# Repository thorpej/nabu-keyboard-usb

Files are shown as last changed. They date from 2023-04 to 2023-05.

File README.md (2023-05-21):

# A NABU Keyboard-to-USB Adapter

(Update: I made a short video about this project!  You can view it
[here](https://youtu.be/F3Tp9NLZv1M).)

This is an adapter that lets you connect a [NABU](https://nabu.ca/) PC
keyboard to any modern computer using USB.  In addition to the keyboard,
it reports the Atari-style joysticks as USB HID gamepads (each as a single
D-pad / hat switch with a single "A" button).

Most of the NABU keys are supported in the obvious way, but it's helpful
to understand how the NABU keyboard works: The keyboard, for the most part,
sends ASCII codes for the keys that are pressed.  It handles CTRL, SHIFT,
and CAPS-LOCK all on its own.  It does not send separate key-down and key-up
events for the standard keys, and it implements key-repeat itself as well.
There are some exceptions, however: the arrow keys (including the **<|||**
and **|||>** keys), **YES**, **NO**, **SYM**, **PAUSE** and **TV/NABU** keys
_do_ send separate key-down and key-up events, and are unaffected by the
normal keyboard modifier keys.  These so-called "special keys" are mapped
to various HID key events as described below.

The physical interface to the NABU keyboard is a DIN-6 connector carrying
a power rail and an RS422 differential transmit line.  The RS422 serial
line runs at 6992 baud, with 8 data bits, 1 stop bit, and no parity.  The
odd-ball bit rate is due to the way the clock is derived; the main clock
frequency in the keyboard is 3.58MHz (the NTSC colorburst frequency), and
the MC6803 microcontroller inside the keyboard internally divides the clock
by 4 to derive its "E" clock.  The firmware in the keyboard then configures
the MC6803's on-board UART to divide E by 128 for the baud clock.
Communication with the keyboard is unidirectional; it is not possible to
send commands to the keyboard.

The keyboard is powered by a nominally-12V-but-actally-9V power supply
provided by the NABU.  The keyboard power comes from the NABU's 12V rail,
but is fed to the keyboard through a large power resistor on the NABU's
mainboard, which drops the voltage to ~9V at the keyboard's steady-state
current draw (documentation says 300mA, but my bench supply tells me
310-320mA).  The keyboard contains an on-board regulator to provide its
own +5V power rail.  In any case, a 9V DC power brick that can supply at
least 500mA should be perfect for the job.  The adapter controls the power
to the NABU using a small power MOSFET connected between the 9V return from
the keyboard and and negative terminal of the power supply.

## How the adapter works

The adapter utilizes the built-in UART and GPIO functionality of the
Raspberry Pi Pico microcontroller.  UART0 is used as the adapter's console
(115200 @ 8N1), UART1 is used to receive data from the keyboard, and one
GPIO pin is used to control the power to the keyboard.  Another GPIO is
sampled at start-up time to enable debug messages; debugging is enabled
when the jumper is installed.

When the adapter starts up, it performs all of the initialization required
and then starts up the second core on the Pico to pull data in from the
keyboard.  This loop running on the second core determines if the data is
for the keyboard or one of the joysticks, and then adds the data byte to
the appropriate input queue.

Meanwhile, the primary core powers up the keyboard and enters its main loop.
This main loop performs 4 basic tasks:
* Blinking the status LED on the Pico to indicate various states of the
  adapter.
* Performing a health check of the keyboard.
* Processing incoming data from the keyboard and generating the appropriate
  USB HID report sequences.
* Calling into the TinyUSB stack to perform device-side USB processing.

### LED task

The LED task is pretty simple and just provides a simple way of reporting
the current status of the adapter at-a-glance.  There are 4 blinking sequences:
* Fast blinking to indicate the adapter is waiting for the host to establish
  a USB session.
* Medium blinking to indicate the adapter is connected to the host but waiting
  for the keyboard to show signs of life.
* A heatbeat pattern to indicate everything is operating normally.
* A slow blinking to indicate the adapter has been suspended and the keyboard
  powered off.

### Keyboard health check task

The health check task (a.k.a. "deadcheck") checks to make sure that we've
heard from the keyboard within the last 5 seconds.  When idle, the keyboard
sends a "ping" approximately every 3.7 seconds.  Whenever the keyboard reader
running on the second core receives a byte of data from the keyboard, it
updates a timestamp, which is checked in deadcheck routine.  If the keyboard
fails to check in for two deadcheck intervals, the adapter reboots the
keyboard by cycling power.

### Data processing task

The data processing task (called _hid_task()_ in the code) pulls data
enqueued by the keyboard reader thread and performs the processing necessary
to generate USB HID report sequences.  In addition to regular keystrokes,
error messages from the keyboard and joystick data are also processed here,
as is remote-host-wakeup if the host system is suspended.

Error processing is actually performed all the time, because the periodic
ping from the keyboard comes in as an error message, as does the notification
of a successful power-on-reset.  Additionally, there are internal hardware
errors (bad RAM / ROM, etc.) as well as user errors (too many keys pressed)
that are reported.  Hardware errors result in rebooting the keyboard by
cycling power.

Because the NABU keyboard generates only a single byte for most key presses,
this task has to generate HID report sequences to correctly report the key.
For example, if we get "A" from the keyboard, we have to generate a sequence
of 4 HID reports: _SHIFT_, _SHIFT_ + _A_, _SHIFT_, _(none)_.  These sequences
are encoded in a table indexed by NABU keyboard code.  All of the regular
keys end with a _(none)_ report.

The special keys are a little different.  They send individual key-down and
key-up events to the adapter, so we are able to simply mirror that behavior
to the host.  Additionally, two of the special keys have been mapped to key
modifiers: **SYM** is mapped to **Meta** (a.k.a. Windows, Command, or GUI).
and the **TV/NABU** key is mapped to **Alt** (a.k.a. Option on Macs).  The
adapter tracks the state of those keys and includes them as modifiers in
keyboard HID reports.

Much to the chargin of Unix users worldwide, the NABU keyboard lacks a
backslash key.  On US keyboards, this key is also used for the "pipe"
character (SHIFT + backslash).  We steal the **YES** and **NO** keys on
the NABU keyboard for these characters: **YES** for pipe, **NO** for
backslash (we have to use two different special keys since special keys
are not affected by the SHIFT keys).  Luckily, because we're using a
special key for **Alt**, we can still type guillemets on a Mac by using
**TV/NABU** plus the **YES** and **NO** keys.  _«Absolument merveilleux !»,
a-t-il déclaré._

Ok! To summarize the special keys:
* **Up**, **Down**, **Left**, and **Right** arrow keys map to their regular
  US keyboard equivalents.
* **<|||** maps to **Page Up** and **|||>** maps to **Page Down** (very
  useful for scrolling in Terminal on macOS).
* **SYM** maps to **Meta**, a.k.a. **Windows**, **Command**, **GUI**,
  **⌘**, etc.
* **TV/NABU** maps to **Alt**, a.k.a. **Option**, **⌥**, etc.
* **NO** maps to **\\**, a.k.a. backslash.
* **YES** maps to **|**, a.k.a. pipe, vertical bar, etc. 

### TinyUSB device task

This is just a call into the TinyUSB library that performs device-side
processing.  From here, various callbacks back into the main adapter code
can be made to fetch descriptors, reports, and set suspend/resume state.

## The hardware

The hardware is very simple and is centered around the Raspberry Pi Pico
microcontroller board, wich provides a UART for the debug console, a UART
for the keyboard interface, the USB interface to the host, and general-
purpose I/O facilities for configuration of the adapter and control of the
keyboard's power supply.

Note that the adapter board has 3 separate power rails: +5V (supplied by
the USB host), +3V3 (from the Pico's on-board regulator), and +9V (from an
external DC power brick, for the keyboard).

### Keyboard input

The keyboard uses RS422 differential signalling, so a SN75176A differential
bus transciever is used to convert the keyboard signalling to a TTL-compatible
signal.  The transient suppression circuitry mimics that present in the NABU
PC.

The output of the SN75176A is at 5V TTL logic levels, but the Pico's I/O
interface operates at 3V3 CMOS logic levels, so a level shifter must be
used.  I just picked the 74LVC245 bus transciever for the job because I
had plenty of them handy, even though it's slight overkill.

The 74LVC245's output is connected to the Rx pin of UART1 on the Pico.
That's pretty much it for the keyboard input.

### Keyboard power supply / control

The board has a 5.5mm x 2.1mm center-positive barrel jack for power input
from an external 9V power brick.  There is a diode in-series with the
positive terminal as reverse-polarity protection.  The positive terminal
from this supply goes stright to the keyboard.  The power return line
from the keyboard is attached to the drain of an IRLU110PBF power MOSFET,
and the MOSFET's source is then connected to the negative terminal of the
supply, which is also connected to the board's ground plane.  The gate is
normally pulled down, but can be driven high by a pin on the Pico to complete
the circuit and power on the keyboard.  The IRLU110PBF was selected for its
current rating, relatively low as far as power MOSFETs go (1V) Vgs threshold,
and < 1 Ohm Rds-ON.  There's nothing particularly special about it otherwise,
and this application isn't especially demanding, so feel free to substitute
your favorite MOSFET (so long as it is in a TO-251-3 package and has a GDS
pin configuration).

### Pin headers

There are 2 pin headers on the board:
* J1 provides access to UART0 on the Pico, so you can see informational or
  debug messages that are logged by the firmware running on the Pico.
* JP1, when connected, enables those fairly verbose debugging messages.  The
  pin is sampled when the adapter starts up, so enabling them requires
  unplugging the adapter from USB and plugging it back in after connecting
  the jumper.

### The board layout

I am definitely an amateur when it comes to PCB design and layout, but I did
try to keep the board fairly small while still making it easy to assemble
(all through-hole parts except for the tab on the power MOSFET which you don't
even _really_ have to solder if that's your preference).  The footprints for
the decoupling caps and suppression caps are fairly forgiving, so if you have
1nF and 100nF caps in your parts bin that fit the footprint, by all means use
them.

You will need to put downward-facing pin headers onto your Pico and install
female pin header stand-offs onto the board.  This is because I squeezed the
power MOSFET and its pulldown resistor under the Pico.  This isn't really
much of a compromise in height since there's a big ol' DIN-6 socket at the
back of the board anyhow.  (The board size is largely dictated by the external
connections.)

Space for sockets for the DIP ICs is provided because I like to use them.
Feel free to elide if that's what floats your boat.

There are a couple of "special" parts on the board:
* The resistors used on the board are fairly small for through-hole resistors,
  selected to reduce space requirements.  Happily, they're readily available
  from Mouser.
* The DIN-6 socket is harder to get than it should be (plenty of panel-mount
  flavors, but not PCB-mount, sigh).  The one I selected was the CLIFF
  FC680806, available from Newark / element14 / Farnell.  The Hirschmann
  930 778-200 may also work, and there's a
  [no-name version on Amazon](https://www.amazon.com/dp/B015IGPKPK)
  that looks like a copy of the CLIFF part.

I expect to make small tweaks to the board over time, but mainly just to get
alignment of various externally-facing parts Just Right(tm) in the event that
some enterprising individual wants to make a 3D-printed enclosure for it
(**_hey, if you want to do this, please get in contact with me!_**).

In addition to the KiCad design files, a PDF version of the schematic and
board images are also provided, along with the Gerber files needed to have
the board made by your favorite PCB fabrication house.

### So what do I need to build one of these things?

Most of the parts required are bog-standard, available from lots of places.
The Raspberry Pi Pico, the DIP sockets, and the male and female pin headers
can all be acquired from Amazon.  If you want nice machined DIP sockets
instead of the cheap stamped kind, you can get those from
[Phoenix Enterprises](https://www.peconnectors.com/sockets-dip-ic-machined/),
but they have a minimum order.  The ceramic capacitors are basic parts,
but I've provided links to specific parts that I know will fit the board
footprints.  I've done the same with the resistors.

* 1 - Raspberry Pi Pico
* 2 - 20x1 2.54mm pin header (for the Pico)
* 1 - 2x1 2.54mm pin header (optional) (for debug jumper)
* 1 - 3x1 2.54mm pin header (optional) (for debug console)
* 2 - 20x1 2.54mm female pin header (to receive the Pico - _cannot be
  low-profile - space beneath the Pico is required_)
* 1 - DIP-20 socket (optional)
* 1 - DIP-8 socket (optional)
* 1 - [SN74LVC245](https://www.mouser.com/ProductDetail/595-SN74LVC245ANE4)
  in DIP-20 package
* 1 - [SN75176A](https://www.mouser.com/ProductDetail/595-SN75176AP) in
  DIP-8 package
* 1 - [IRLU110PBF](https://www.mouser.com/ProductDetail/844-IRLU110PBF) or
  equivalent power MOSFET in TO-251-3 package with GDS pin configuration
* 2 - [100nF / 0.1µF ceramic capacitor](https://www.mouser.com/ProductDetail/581-SR215E104MAR)
* 2 - [1nF / 1000pF ceramic capacitor](https://www.mouser.com/ProductDetail/581-SR215A102JARTR1)
* 1 - [180 Ohm resistor](https://www.mouser.com/ProductDetail/603-MFR50SFTE52-180R) that fits in a DIN0207 vertical footprint.
* 1 - [10K Ohm resistor](https://www.mouser.com/ProductDetail/603-MFR50SFTE52-10K) that fits in a DIN0207 horizontal footprint.
* 1 - 1N4001 diode in the standard package.  You can actually use whatever diode floats your boat here (it's not involved in
  any switching, merely used for reverse polarity protection), so long as it has > 18V reverse voltage rating and a 500mA current
  rating.
* 1 - [PCB-mount 5.5mm x 2.1mm DC barrel jack](https://www.mouser.com/ProductDetail/163-179PH-EX)
* 1 - [PCB-mount DIN-6 jack, CLIFF FC680806 or equivalent](https://www.newark.com/cliff-electronic-components/fc680806/din-audio-video-conn-jack-6pos/dp/99AC9154).  Also available [here!](https://www.tme.com/us/en-us/details/fc680806/din-connectors/cliff/d6-fc680806/)
* 1 - [9V @ 500mA-or-better DC power brick with 5.5mm x 2.1mm barrel connector](https://www.mouser.com/ProductDetail/490-SWI12-9-N-P5)
* 1 - Micro-USB cable for connecting the adapter to your computer.

### Assembling the board

You might have your own favorite way of putting these things together.  If
so, hey, you do you!  But for those of you who don't, let me recommend a
few basic pointers that will help making the going a little easier.  I'm
going to assume that you already know the basics of soldering.

First, it's best to assemble the lowest-profile components first, increasing
the height of the board as you go along.  With that in mind, here is the
order I would recommend:

1. R1 and Q1 (the parts that sit beneath the Pico)
2. D1
3. U1 and U3 (or their sockets)
4. C1, C2, C3, and C4
5. R2 (the vertically-mounted resistor next to C3 and C4)
6. Female pin heders for U2 (the Pico)
7. J1 and JP1 (the male pin headers)
8. J3 (the DC barrel jack)
9. J2 (the DIN-6 jack)

If you already installed the pin headers into your Pico, or bought the Pico
with the pin headers pre-installed (hopefully with the long end of the pins
facing downwards), then cool!  Otherwise, a trick that makes it easy is to
place the pin headers into the Pico (with the plastic holder on the bottom
of the Pico and the short end of the pins poking through the Pico board) and
then press that as a unit into the female headers installed on the adapter
board.  That will hold everything steady while you solder the pin headers
to the Pico itself.

### Programming the Pico with the NABU Keyboard to USB firmware

Ok, so you've built the board, now you need to get the firmware onto the Pico.
This is easy!  There's a small button on the Pico board.  What you need to do
is to hold that button down while you connect the Pico to your computer using
the USB cable.  When you do that, the Pico will appear on your computer as a
hard drive with a FAT file system on it named "RPI-RP2" (exactly how this
appears on your computer is left as an exercise to the reader).  All you need
to do is copy the provided **_nabu_keyboard_usb.uf2_** file onto that file
system _et voilà!_ your Pico is programmed and has now attached itself as a
USB HID device with 1 keyboard interface and 2 game pad interfaces!

Once you've programmed the Pico, you're all set.  At this point, I recommend
unplugging it from the computer before attaching the 9V power brick and NABU
keyboard.  Once everything is cabled up, plug the Pico back into your computer
and enjoy typing on those sweet, sweet ALPS key switches!

I hope you have fun with your NABU and I hope you enjoy this silly little
project of mine!  If you end up playing with it, I'd love to hear from you!
You can find me on [Mastodon](https://mastodon.sdf.org/@thorpej)
and on [Twitter](https://twitter.com/thorpej) (for as long as it lasts,
anyway).

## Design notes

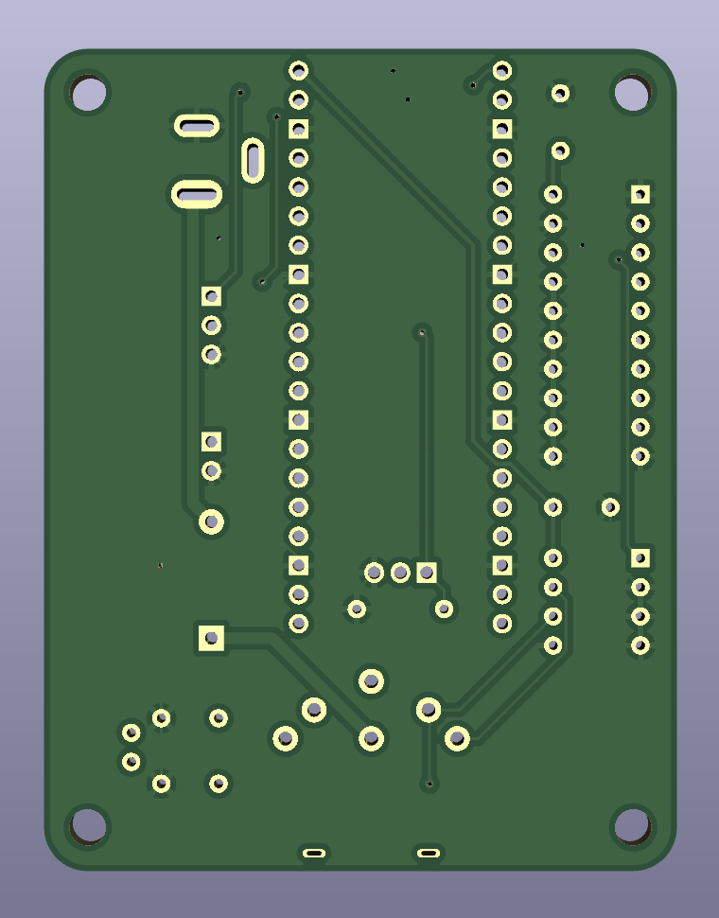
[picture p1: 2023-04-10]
design-files/nabu-keyboard-usb-pcb-back.png

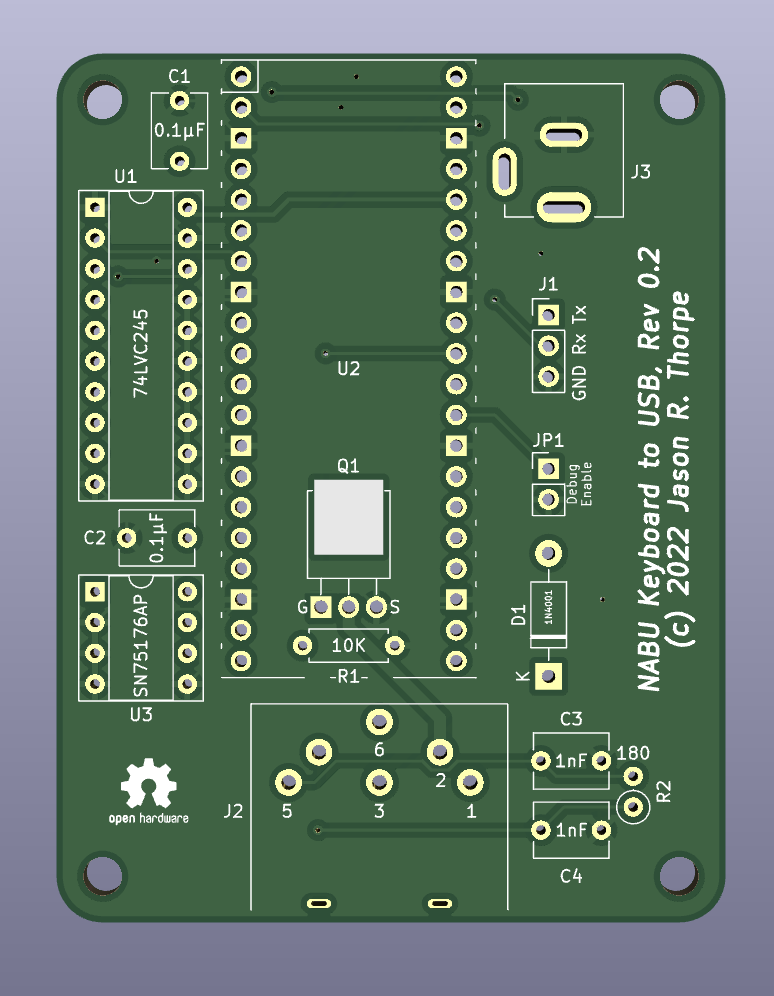
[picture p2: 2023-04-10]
design-files/nabu-keyboard-usb-pcb-front.png

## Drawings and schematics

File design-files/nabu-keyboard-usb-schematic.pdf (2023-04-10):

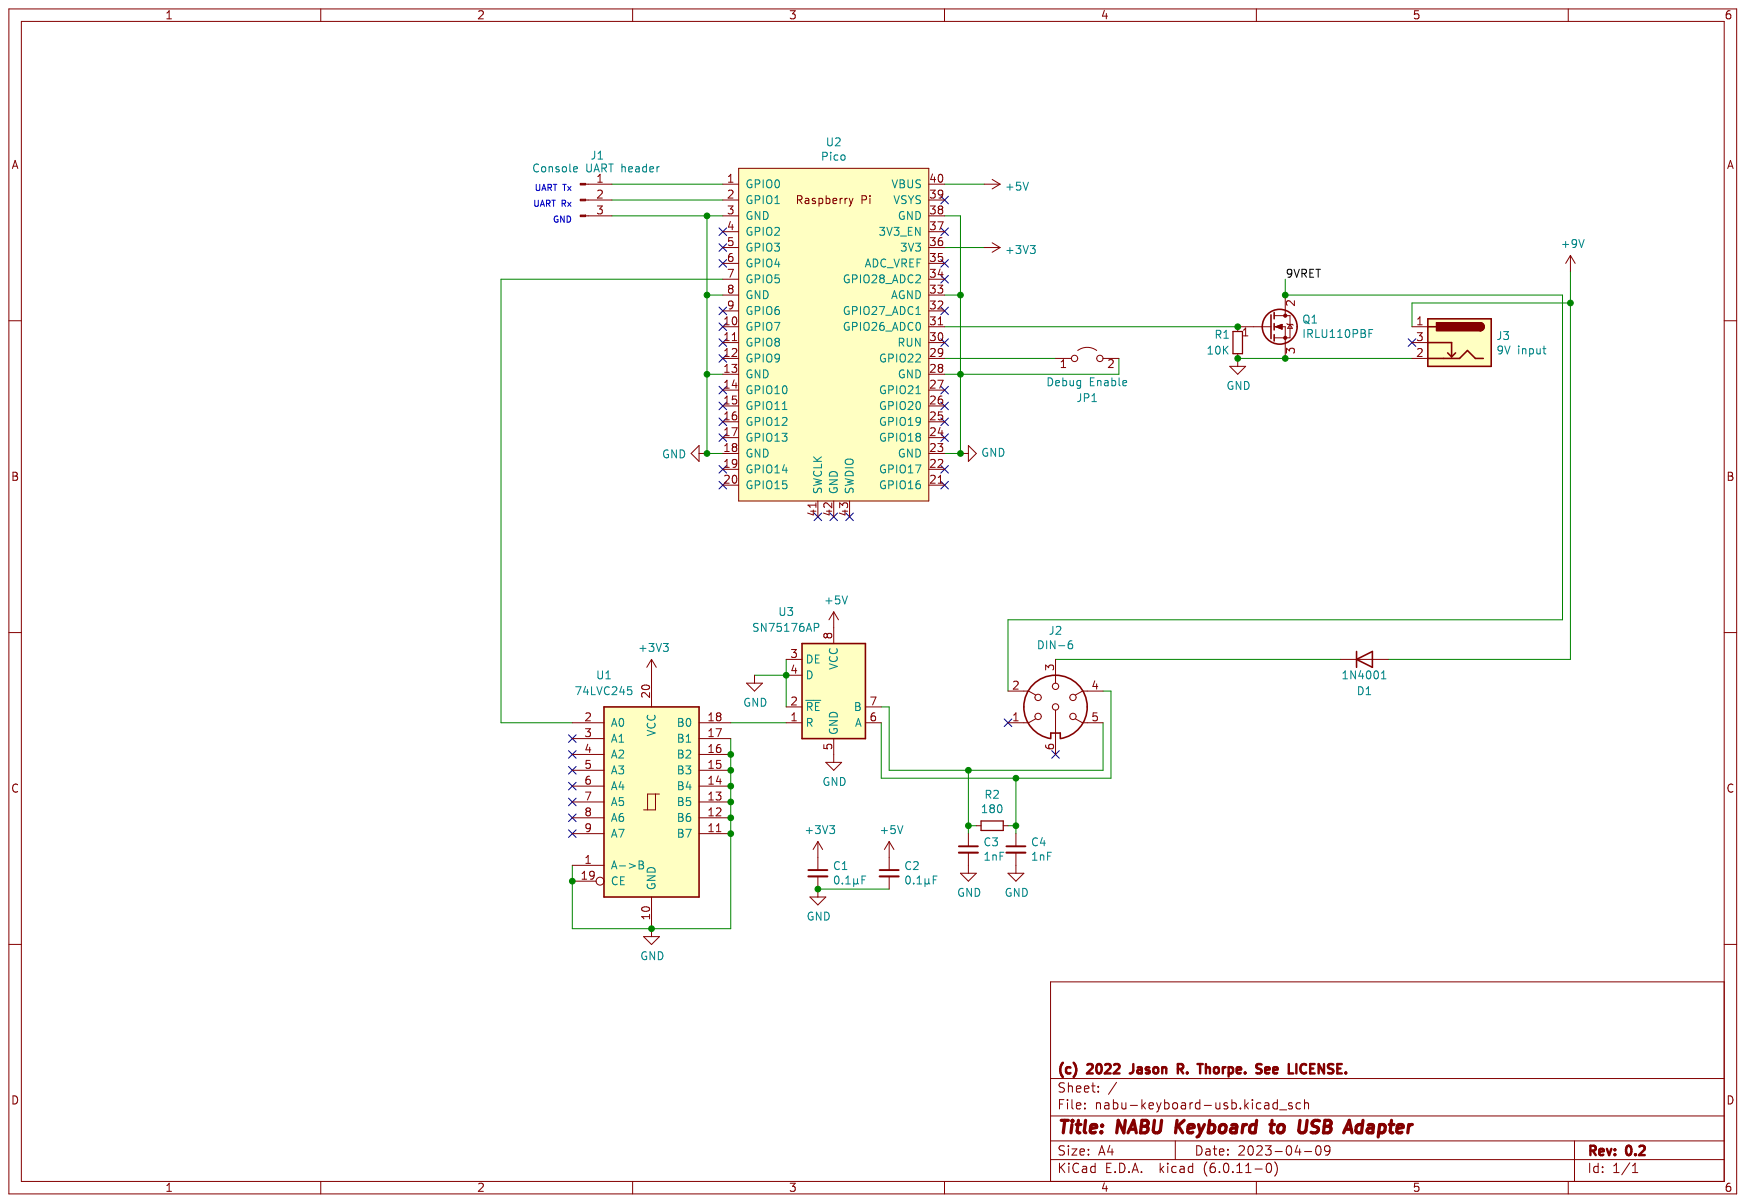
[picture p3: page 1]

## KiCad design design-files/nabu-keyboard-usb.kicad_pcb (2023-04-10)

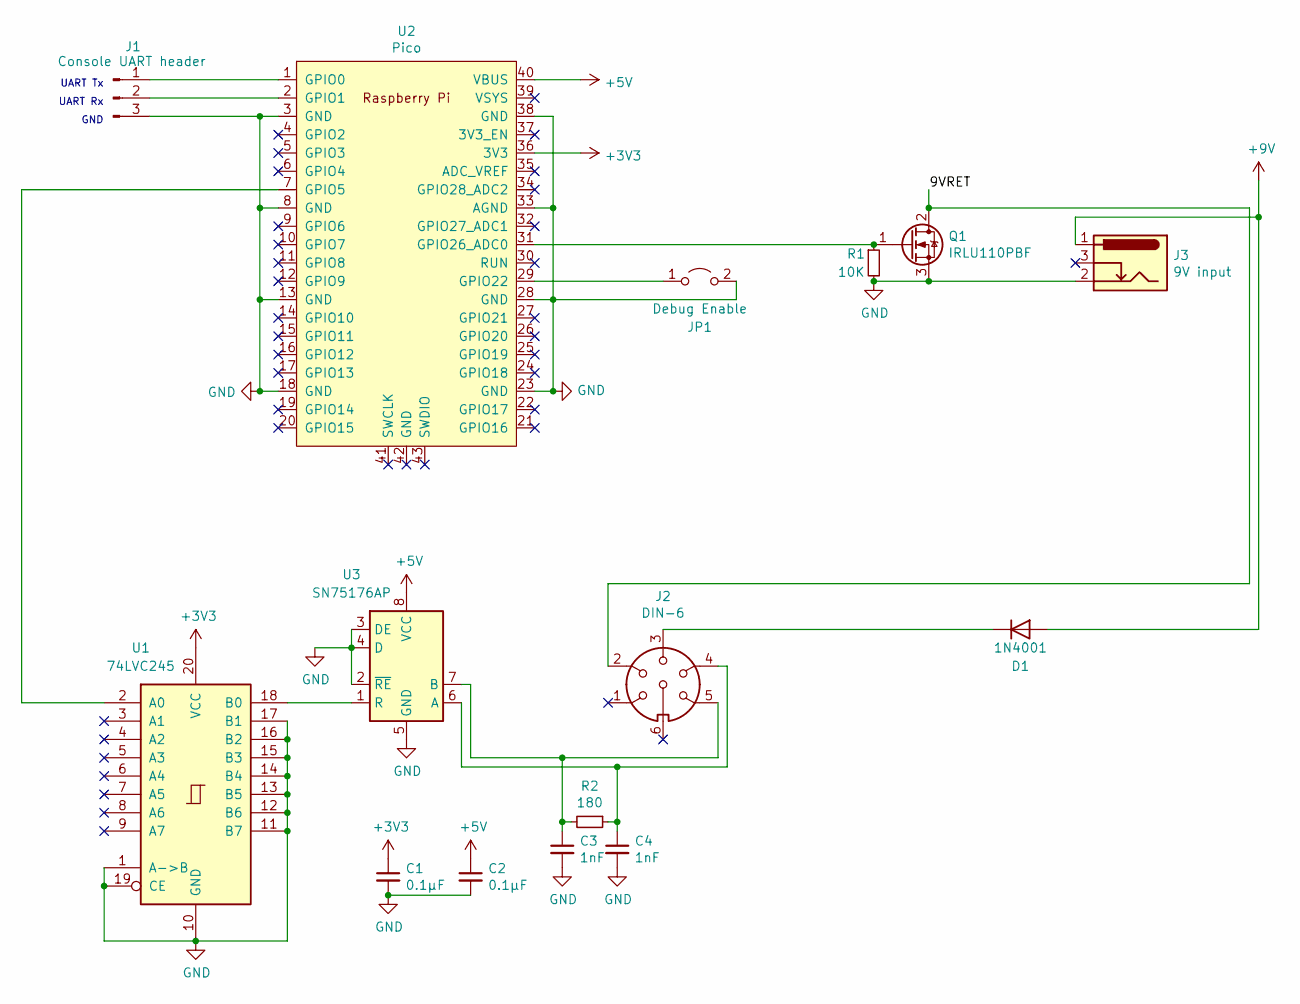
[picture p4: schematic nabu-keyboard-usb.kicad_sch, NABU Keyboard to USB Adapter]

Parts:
C1, C2: 0.1µF; C_Disc_D6.0mm_W4.4mm_P5.00mm
C3, C4: 1nF; C_Disc_D6.0mm_W4.4mm_P5.00mm
D1: 1N4001; D_DO-41_SOD81_P10.16mm_Horizontal
J1: Console UART header; PinHeader_1x03_P2.54mm_Vertical
J2: DIN-6; Jack_DIN-6_CLIFF_FC680806
J3: 9V input; Kobiconn_163-179PH-EX-5_5-2_1mm-1_5A
JP1: Debug Enable; PinHeader_1x02_P2.54mm_Vertical
Q1: IRLU110PBF; TO-251-3-1EP_Horizontal_TabDown
R1: 10K; R_Axial_DIN0207_L6.3mm_D2.5mm_P7.62mm_Horizontal; Part YAGEO MFR50SFTE52-10K
R2: 180; R_Axial_DIN0207_L6.3mm_D2.5mm_P2.54mm_Vertical; Part YAGEO MFR50SFTE52-180R
U1: 74LVC245; DIP-20_W7.62mm_Socket
U2: Pico; RPi_Pico_TH
U3: SN75176AP; DIP-8_W7.62mm_Socket

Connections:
+3V3: C1.1, U1.20 (VCC), U2.36 (3V3)
+5V: C2.1, U2.40 (VBUS), U3.8 (VCC)
+9V: D1.2 (A), J3.1
/9VRET: J2.2, Q1.2 (D)
GND: C1.2, C2.2, C3.2, C4.2, J1.3, J3.2, JP1.2 (B), Q1.3 (S), R1.2, U1.1 (A->B), U1.10 (GND), U1.11 (B7), U1.12 (B6), U1.13 (B5), U1.14 (B4), U1.15 (B3), U1.16 (B2), U1.17 (B1), U1.19 (CE), U2.3 (GND), U2.8 (GND), U2.13 (GND), U2.18 (GND), U2.23 (GND), U2.28 (GND), U2.33 (AGND), U2.38 (GND), U3.2 (~RE), U3.3 (DE), U3.4 (D), U3.5 (GND)
unnamed: D1.1 (K), J2.3
unnamed: J1.1, U2.1 (GPIO0)
unnamed: J1.2, U2.2 (GPIO1)
unnamed: JP1.1 (A), U2.29 (GPIO22)
unnamed: Q1.1 (G), R1.1, U2.31 (GPIO26_ADC0)
unnamed: U1.2 (A0), U2.7 (GPIO5)
unnamed: U1.18 (B0), U3.1 (R)
unnamed: C4.1, J2.4, R2.1, U3.6 (A)
unnamed: C3.1, J2.5, R2.2, U3.7 (B)

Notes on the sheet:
GND
UART Tx
UART Rx

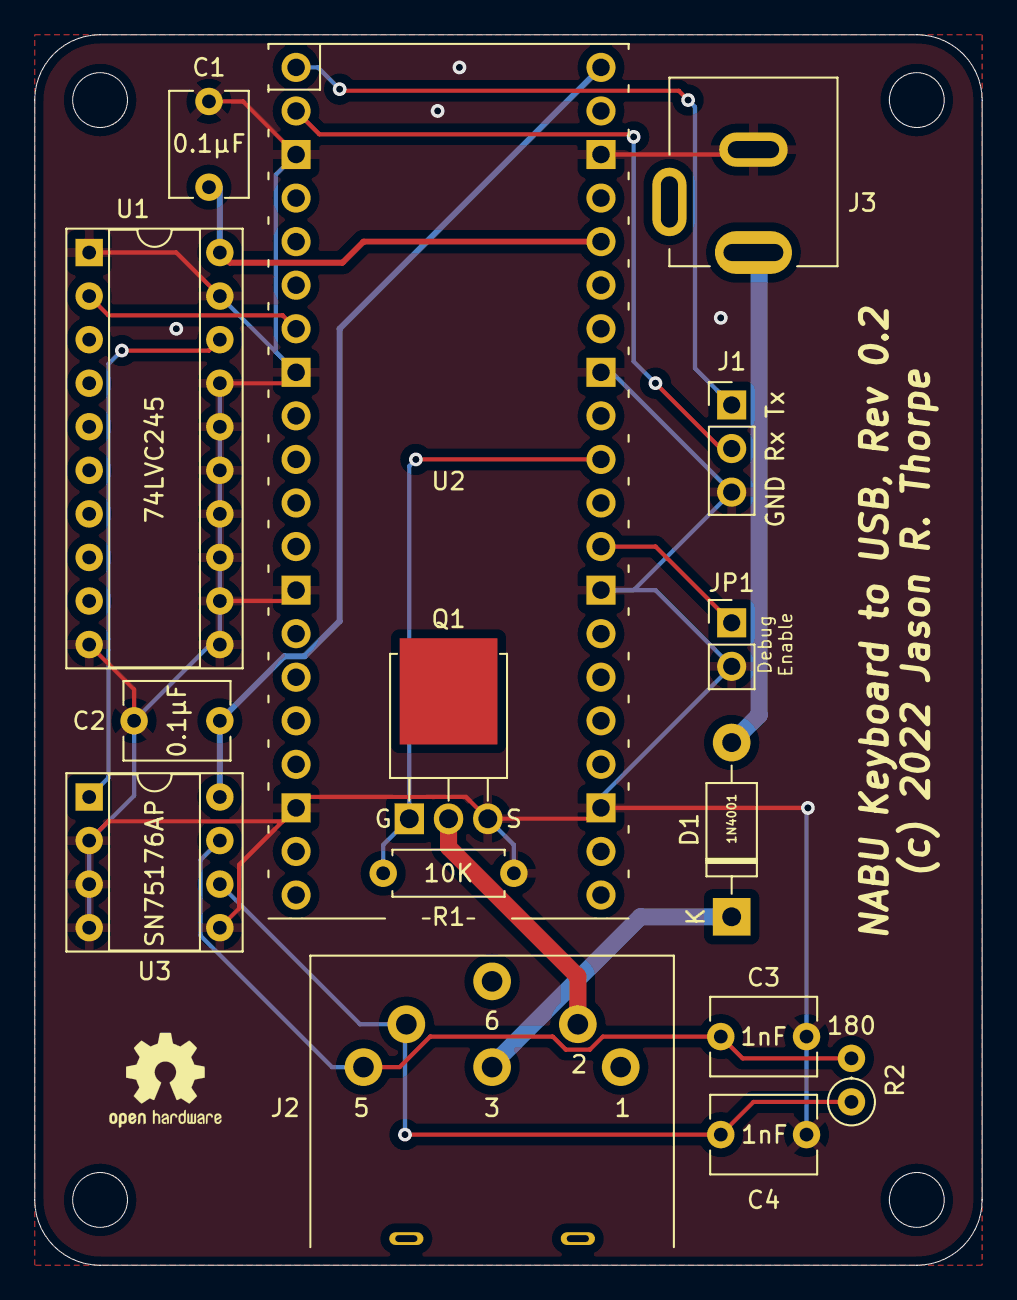
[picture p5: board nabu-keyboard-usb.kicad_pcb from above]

Board: 2 copper layers, 55.2 x 71.8 mm, 15 parts (0 on the bottom side), 14 nets.

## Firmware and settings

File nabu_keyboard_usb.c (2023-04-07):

/*-
 * Copyright (c) 2022 Jason R. Thorpe.
 * All rights reserved.
 *
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
 * THIS SOFTWARE IS PROVIDED BY THE AUTHOR ``AS IS'' AND ANY EXPRESS OR
 * IMPLIED WARRANTIES, INCLUDING, BUT NOT LIMITED TO, THE IMPLIED WARRANTIES
 * OF MERCHANTABILITY AND FITNESS FOR A PARTICULAR PURPOSE ARE DISCLAIMED.
 * IN NO EVENT SHALL THE AUTHOR BE LIABLE FOR ANY DIRECT, INDIRECT,
 * INCIDENTAL, SPECIAL, EXEMPLARY, OR CONSEQUENTIAL DAMAGES (INCLUDING,
 * BUT NOT LIMITED TO, PROCUREMENT OF SUBSTITUTE GOODS OR SERVICES;
 * LOSS OF USE, DATA, OR PROFITS; OR BUSINESS INTERRUPTION) HOWEVER CAUSED
 * AND ON ANY THEORY OF LIABILITY, WHETHER IN CONTRACT, STRICT LIABILITY,
 * OR TORT (INCLUDING NEGLIGENCE OR OTHERWISE) ARISING IN ANY WAY
 * OUT OF THE USE OF THIS SOFTWARE, EVEN IF ADVISED OF THE POSSIBILITY OF
 * SUCH DAMAGE.
 */

/*
 * NABU Keyboard to USB Adapter
 *
 * This interfaces a NABU PC keyboard as a USB keyboard device
 * with the standard US layout.
 *
 * For the most part, the NABU keyboard reports keys as ASCII characters.
 * There are no key-down or key-up events except for some special keys.
 * Shift, Control, and CapsLock are not themselves reported.  The keyboard
 * itself implements auto-repeat.
 *
 * Joystick data is also reported by the NABU keyboard.
 *
 * The NABU keyboard physical layer is RS422 8N1 @ 6992 baud.
 * (Yes, it's weird, because it's derived from the 3.58MHz NTSC
 * colorburst frequency - 3.58MHz input to 6803 which internally
 * divides by 4 to generate E, and the internal UART is configured
 * to use the /128 clock divisor to get the baud clock.)
 *
 * We use UART1 on the Pico to receive data from the keyboard.  UART0
 * is used as the console port for debugging purposes.
 *
 * TODO:
 * - Handle the host requesting Boot protocol (rather than Report protocol).
 */

/* Pico SDK headers */
#include "pico/stdlib.h"
#include "pico/printf.h"
#include "pico/sync.h"
#include "pico/time.h"
#include "pico/multicore.h"
#include "hardware/uart.h"

/* TinyUSB SDK headers */
#include "bsp/board.h"
#include "tusb.h"

/* Standard headers */
#include <string.h>

/* Local headers */

/*
 * GP22 (physical pin 29 on the DIP-40 Pico) is a debug-enable strapping
 * pin that we sample when we launch.  It's pulled-up internally; strap
 * to ground to enable debug messages.
 */
#define	DEBUG_STRAP_PIN		22

static bool debug_enabled;
#define	debug_printf(...)					\
	do {							\
		if (debug_enabled) {				\
			printf(__VA_ARGS__);			\
		}						\
	} while (/*CONSTCOND*/0)

/*
 * GPIO pins 4 and 5 are used for UART1 TX and RX, respectively.
 * This maps to physical pins 6 and 7 on the DIP-40 Pico.
 */
#define	UART1_TX_PIN		4
#define	UART1_RX_PIN		5

/*
 * GP26 (physical pin 31 on the DIP-40 Pico) is connected to the gate
 * of a power MOSFET that sits between the keyboard V- and GND.  Driving
 * GP26 high completes the keyboard power supply circuit powers it on.
 */
#define	PWREN_PIN		26

/*
 * Circular queue between the the UART receiver and the USB sender.
 */

#define	QUEUE_SIZE		64
#define	QUEUE_MASK		(QUEUE_SIZE - 1)
#define	QUEUE_NEXT(n)		(((n) + 1) & QUEUE_MASK)
#define	QUEUE_EMPTY_P(q)	((q)->cons == (q)->prod)
#define	QUEUE_FULL_P(q)		(QUEUE_NEXT((q)->prod) == (q)->cons)

struct queue {
	mutex_t		mutex;
	unsigned int	prod;
	unsigned int	cons;
	uint8_t		data[QUEUE_SIZE];
};

static void
queue_init(struct queue *q)
{
	memset(q, 0, sizeof(*q));
	mutex_init(&q->mutex);
}

static bool
queue_add(struct queue *q, uint8_t v)
{
	bool rv = true;		/* "OK!" is the common-case. */

	mutex_enter_blocking(&q->mutex);
	if (! QUEUE_FULL_P(q)) {
		q->data[q->prod] = v;
		q->prod = QUEUE_NEXT(q->prod);
	} else {
		rv = false;
	}
	mutex_exit(&q->mutex);

	return rv;
}

static bool
queue_consume(struct queue *q, uint8_t *vp, bool advance)
{
	bool rv = false;

	mutex_enter_blocking(&q->mutex);
	if (! QUEUE_EMPTY_P(q)) {
		*vp = q->data[q->cons];
		if (advance) {
			q->cons = QUEUE_NEXT(q->cons);
		}
		rv = true;
	}
	mutex_exit(&q->mutex);

	return rv;
}

static bool
queue_peek(struct queue *q, uint8_t *vp)
{
	return queue_consume(q, vp, false);
}

static bool
queue_get(struct queue *q, uint8_t *vp)
{
	return queue_consume(q, vp, true);
}

static void
queue_drain(struct queue *q)
{
	mutex_enter_blocking(&q->mutex);
	q->prod = q->cons = 0;
	mutex_exit(&q->mutex);
}

static bool suspended = false;
static bool mounted = false;
static bool want_remote_wakeup = false;
static bool have_nabu = false;

/*
 * LED blinking patterns.  Even indices are ON time, odd indices are
 * OFF time.  -1 means "go back to beginning".
 */

/* 250ms on, 250ms off */
static const int ledseq_not_mounted[] = {
	250, 250, -1
};

/* 1000ms on, 1000ms off */
static const int ledseq_wait_nabu[] = {
	1000, 1000, -1
};

/* Heartbeat pattern. */
static const int ledseq_healthy[] = {
	100, 300, 100, 1000, -1
};

/* 2500ms on, 2500ms off */
static const int ledseq_suspended[] = {
	2500, 2500, -1
};

struct {
	const int *sequence;
	uint idx;
	uint32_t start_ms;
	bool state;
} led_context;

static void
led_set_sequence(const int *seq)
{
	if (led_context.sequence == seq) {
		return;
	}

	led_context.sequence = seq;
	led_context.idx = 0;
	led_context.start_ms = board_millis();
	led_context.state = true;

	board_led_write(led_context.state);
}

static void
led_select_sequence(void)
{
	if (led_context.sequence == NULL) {
		return;
	}

	if (!mounted) {
		led_set_sequence(ledseq_not_mounted);
		return;
	}

	if (suspended && !want_remote_wakeup) {
		led_set_sequence(ledseq_suspended);
		return;
	}

	if (have_nabu) {
		led_set_sequence(ledseq_healthy);
		return;
	}

	led_set_sequence(ledseq_wait_nabu);
}

static void
led_task(uint32_t now)
{
	int interval;

	if (led_context.sequence == NULL) {
		return;
	}

	interval = led_context.sequence[led_context.idx];

	if (now - led_context.start_ms < interval) {
		return;
	}

	led_context.start_ms += interval;

	if ((interval = led_context.sequence[++led_context.idx]) == -1) {
		interval = led_context.sequence[0];
		led_context.idx = 0;
	}

	led_context.state ^= true;

	board_led_write(led_context.state);
}

/*
 * Map NABU keycodes to HID key codes.
 *
 * The HID Report array sends a report for each modifier key, in the
 * seqence they are pressed / released.  So, an 'A' is:
 *
 *	Shift, Shift + A, Shift, none
 *
 * We encode these sequences directly in the map.  The final entry in
 * each sequence is always 0.  For keys where we get individual Down/Up
 * events from the NABU keyboard, we don't use sequences, we just send
 * the individual event (those keys aren't affected by modifiers).
 *
 * Unassigned entries get 0, which conveniently is HID_KEY_NONE.  N.B.
 * the NABU keyboard reader thread won't even enqueue keystroke events
 * for these unassigned keys.
 */

#define	M_CTRL		0x0100		/* KEYBOARD_MODIFIER_LEFTCTRL << 8 */
#define	M_SHIFT		0x0200		/* KEYBOARD_MODIFIER_LEFTSHIFT << 8 */
#define	M_ALT		0x0400		/* KEYBOARD_MODIFIER_LEFTALT << 8 */
#define	M_META		0x0800		/* KEYBOARD_MODIFIER_LEFTGUI << 8 */
#define	M_DOWN		0x1000
#define	M_UP		0x2000
#define	M_ENDSEQ	0x4000

#define	M_HIDKEY(m)	((m) & 0x00ff)
#define	M_MODS(m)	((m) & 0x0f00)

#define	NABU_CODE_JOY0		0x80
#define	NABU_CODE_JOY1		0x81
#define	NABU_CODE_ERR_FIRST	0x90
#define	NABU_CODE_ERR_LAST	0x95
#define	NABU_CODE_JOYDAT_FIRST	0xa0
#define	NABU_CODE_JOYDAT_LAST	0xbf

#define	NABU_CODE_JOYDAT_P(c)	((c) >= NABU_CODE_JOYDAT_FIRST &&	\
				 (c) <= NABU_CODE_JOYDAT_LAST)

#define	NABU_CODE_ERR_P(c)	((c) >= NABU_CODE_ERR_FIRST &&		\
				 (c) <= NABU_CODE_ERR_LAST)

#define	NABU_CODE_ERR_MKEY	0x90	/* multiple keys pressed */
#define	NABU_CODE_ERR_RAM	0x91	/* faulty keyboard RAM */
#define	NABU_CODE_ERR_ROM	0x92	/* faulty keyboard ROM */
#define	NABU_CODE_ERR_ISR	0x93	/* illegal ISR (?) */
#define	NABU_CODE_ERR_PING	0x94	/* periodic no-load ping */
#define	NABU_CODE_ERR_RESET	0x95	/* keyboard power-up/reset */

#define	NABU_KBD_BAUDRATE	6992

struct codeseq {
	uint16_t codes[6];	/* 0-terminated */
};

static const struct codeseq nabu_to_hid[256] = {
/*
 * CTRL just lops off the 2 upper bits of the keycode
 * on the NABU keyboard (except for C-'<' ??), but we
 * simplify to C-a, C-c, etc.
 */
[0x00]		=	{ { M_CTRL,				/* C-'@' */
			    M_CTRL | M_SHIFT,
			    M_CTRL | M_SHIFT | HID_KEY_2,
			    M_CTRL | M_SHIFT,
			    M_CTRL } },
[0x01]		=	{ { M_CTRL,
			    M_CTRL | HID_KEY_A,
			    M_CTRL } },
[0x02]		=	{ { M_CTRL,
			    M_CTRL | HID_KEY_B,
			    M_CTRL } },
[0x03]		=	{ { M_CTRL,
			    M_CTRL | HID_KEY_C,
			    M_CTRL } },
[0x04]		=	{ { M_CTRL,
			    M_CTRL | HID_KEY_D,
			    M_CTRL } },
[0x05]		=	{ { M_CTRL,
			    M_CTRL | HID_KEY_E,
			    M_CTRL } },
[0x06]		=	{ { M_CTRL,
			    M_CTRL | HID_KEY_F,
			    M_CTRL } },
[0x07]		=	{ { M_CTRL,
			    M_CTRL | HID_KEY_G,
			    M_CTRL } },
[0x08]		=	{ { HID_KEY_BACKSPACE } },		/* Backspace */
[0x09]		=	{ { HID_KEY_TAB } },			/* Tab */
[0x0a]		=	{ { HID_KEY_ENTER } },			/* LF */
[0x0b]		=	{ { M_CTRL,
			    M_CTRL | HID_KEY_K,
			    M_CTRL } },
[0x0c]		=	{ { M_CTRL,
			    M_CTRL | HID_KEY_L,
			    M_CTRL } },
[0x0d]		=	{ { HID_KEY_ENTER } },			/* CR */
[0x0e]		=	{ { M_CTRL,
			    M_CTRL | HID_KEY_N,
			    M_CTRL } },
[0x0f]		=	{ { M_CTRL,
			    M_CTRL | HID_KEY_O,
			    M_CTRL } },
[0x10]		=	{ { M_CTRL,
			    M_CTRL | HID_KEY_P,
			    M_CTRL } },
[0x11]		=	{ { M_CTRL,
			    M_CTRL | HID_KEY_Q,
			    M_CTRL } },
[0x12]		=	{ { M_CTRL,
			    M_CTRL | HID_KEY_R,
			    M_CTRL } },
[0x13]		=	{ { M_CTRL,
			    M_CTRL | HID_KEY_S,
			    M_CTRL } },
[0x14]		=	{ { M_CTRL,
			    M_CTRL | HID_KEY_T,
			    M_CTRL } },
[0x15]		=	{ { M_CTRL,
			    M_CTRL | HID_KEY_U,
			    M_CTRL } },
[0x16]		=	{ { M_CTRL,
			    M_CTRL | HID_KEY_V,
			    M_CTRL } },
[0x17]		=	{ { M_CTRL,
			    M_CTRL | HID_KEY_W,
			    M_CTRL } },
[0x18]		=	{ { M_CTRL,
			    M_CTRL | HID_KEY_X,
			    M_CTRL } },
[0x19]		=	{ { M_CTRL,
			    M_CTRL | HID_KEY_Y,
			    M_CTRL } },
[0x1a]		=	{ { M_CTRL,
			    M_CTRL | HID_KEY_Z,
			    M_CTRL } },
[0x1b]		=	{ { HID_KEY_ESCAPE } },			/* ESC */
[0x1c]		=	{ { M_CTRL,				/* C-'<' */
			    M_CTRL | M_SHIFT,
			    M_CTRL | M_SHIFT | HID_KEY_COMMA,
			    M_CTRL | M_SHIFT,
			    M_CTRL } },
[0x1d]		=	{ { M_CTRL,
			    M_CTRL | HID_KEY_BRACKET_RIGHT,
			    M_CTRL } },
[0x1e]		=	{ { M_CTRL,				/* C-'^' */
			    M_CTRL | M_SHIFT,
			    M_CTRL | M_SHIFT | HID_KEY_6,
			    M_CTRL | M_SHIFT,
			    M_CTRL } },
[0x1f]		=	{ { M_CTRL,				/* C-'_' */
			    M_CTRL | M_SHIFT,
			    M_CTRL | M_SHIFT | HID_KEY_MINUS,
			    M_CTRL | M_SHIFT,
			    M_CTRL } },

[0x20]		=	{ { HID_KEY_SPACE } },
[0x21]		=	{ { M_SHIFT,				/* ! */
			    M_SHIFT | HID_KEY_1,
			    M_SHIFT } },
[0x22]		=	{ { M_SHIFT,				/* " */
			    M_SHIFT | HID_KEY_APOSTROPHE,
			    M_SHIFT } },
[0x23]		=	{ { M_SHIFT,				/* # */
			    M_SHIFT | HID_KEY_3,
			    M_SHIFT } },
[0x24]		=	{ { M_SHIFT,				/* $ */
			    M_SHIFT | HID_KEY_4,
			    M_SHIFT } },
[0x25]		=	{ { M_SHIFT,				/* % */
			    M_SHIFT | HID_KEY_5,
			    M_SHIFT } },
[0x26]		=	{ { M_SHIFT,				/* & */
			    M_SHIFT | HID_KEY_7,
			    M_SHIFT } },
[0x27]		=	{ { HID_KEY_APOSTROPHE } },
[0x28]		=	{ { M_SHIFT,				/* ( */
			    M_SHIFT | HID_KEY_9,
			    M_SHIFT } },
[0x29]		=	{ { M_SHIFT,				/* ) */
			    M_SHIFT | HID_KEY_0,
			    M_SHIFT } },
[0x2a]		=	{ { M_SHIFT,				/* * */
			    M_SHIFT | HID_KEY_8,
			    M_SHIFT } },
[0x2b]		=	{ { M_SHIFT,				/* + */
			    M_SHIFT | HID_KEY_EQUAL,
			    M_SHIFT } },
[0x2c]		=	{ { HID_KEY_COMMA } },			/* , */
[0x2d]		=	{ { HID_KEY_MINUS } },			/* - */
[0x2e]		=	{ { HID_KEY_PERIOD } },			/* . */
[0x2f]		=	{ { HID_KEY_SLASH } },			/* / */
[0x30]		=	{ { HID_KEY_0 } },
[0x31]		=	{ { HID_KEY_1 } },
[0x32]		=	{ { HID_KEY_2 } },
[0x33]		=	{ { HID_KEY_3 } },
[0x34]		=	{ { HID_KEY_4 } },
[0x35]		=	{ { HID_KEY_5 } },
[0x36]		=	{ { HID_KEY_6 } },
[0x37]		=	{ { HID_KEY_7 } },
[0x38]		=	{ { HID_KEY_8 } },
[0x39]		=	{ { HID_KEY_9 } },
[0x3a]		=	{ { M_SHIFT,				/* : */
			    M_SHIFT | HID_KEY_SEMICOLON,
			    M_SHIFT } },
[0x3b]		=	{ { HID_KEY_SEMICOLON } },
[0x3c]		=	{ { M_SHIFT,				/* < */
			    M_SHIFT | HID_KEY_COMMA,
			    M_SHIFT } },
[0x3d]		=	{ { HID_KEY_EQUAL } },
[0x3e]		=	{ { M_SHIFT,				/* > */
			    M_SHIFT | HID_KEY_PERIOD,
			    M_SHIFT } },
[0x3f]		=	{ { M_SHIFT,				/* ? */
			    M_SHIFT | HID_KEY_SLASH,
			    M_SHIFT } },

[0x40]		=	{ { M_SHIFT,				/* @ */
			    M_SHIFT | HID_KEY_2,
			    M_SHIFT } },
[0x41]		=	{ { M_SHIFT,
			    M_SHIFT | HID_KEY_A,
			    M_SHIFT } },
[0x42]		=	{ { M_SHIFT,
			    M_SHIFT | HID_KEY_B,
			    M_SHIFT } },
[0x43]		=	{ { M_SHIFT,
			    M_SHIFT | HID_KEY_C,
			    M_SHIFT } },
[0x44]		=	{ { M_SHIFT,
			    M_SHIFT | HID_KEY_D,
			    M_SHIFT } },
[0x45]		=	{ { M_SHIFT,
			    M_SHIFT | HID_KEY_E,
			    M_SHIFT } },
[0x46]		=	{ { M_SHIFT,
			    M_SHIFT | HID_KEY_F,
			    M_SHIFT } },
[0x47]		=	{ { M_SHIFT,
			    M_SHIFT | HID_KEY_G,
			    M_SHIFT } },
[0x48]		=	{ { M_SHIFT,
			    M_SHIFT | HID_KEY_H,
			    M_SHIFT } },
[0x49]		=	{ { M_SHIFT,
			    M_SHIFT | HID_KEY_I,
			    M_SHIFT } },
[0x4a]		=	{ { M_SHIFT,
			    M_SHIFT | HID_KEY_J,
			    M_SHIFT } },
[0x4b]		=	{ { M_SHIFT,
			    M_SHIFT | HID_KEY_K,
			    M_SHIFT } },
[0x4c]		=	{ { M_SHIFT,
			    M_SHIFT | HID_KEY_L,
			    M_SHIFT } },
[0x4d]		=	{ { M_SHIFT,
			    M_SHIFT | HID_KEY_M,
			    M_SHIFT } },
[0x4e]		=	{ { M_SHIFT,
			    M_SHIFT | HID_KEY_N,
			    M_SHIFT } },
[0x4f]		=	{ { M_SHIFT,
			    M_SHIFT | HID_KEY_O,
			    M_SHIFT } },
[0x50]		=	{ { M_SHIFT,
			    M_SHIFT | HID_KEY_P,
			    M_SHIFT } },
[0x51]		=	{ { M_SHIFT,
			    M_SHIFT | HID_KEY_Q,
			    M_SHIFT } },
[0x52]		=	{ { M_SHIFT,
			    M_SHIFT | HID_KEY_R,
			    M_SHIFT } },
[0x53]		=	{ { M_SHIFT,
			    M_SHIFT | HID_KEY_S,
			    M_SHIFT } },
[0x54]		=	{ { M_SHIFT,
			    M_SHIFT | HID_KEY_T,
			    M_SHIFT } },
[0x55]		=	{ { M_SHIFT,
			    M_SHIFT | HID_KEY_U,
			    M_SHIFT } },
[0x56]		=	{ { M_SHIFT,
			    M_SHIFT | HID_KEY_V,
			    M_SHIFT } },
[0x57]		=	{ { M_SHIFT,
			    M_SHIFT | HID_KEY_W,
			    M_SHIFT } },
[0x58]		=	{ { M_SHIFT,
			    M_SHIFT | HID_KEY_X,
			    M_SHIFT } },
[0x59]		=	{ { M_SHIFT,
			    M_SHIFT | HID_KEY_Y,
			    M_SHIFT } },
[0x5a]		=	{ { M_SHIFT,
			    M_SHIFT | HID_KEY_Z,
			    M_SHIFT } },
[0x5b]		=	{ { HID_KEY_BRACKET_LEFT } },		/* [ */
/* 0x5c */
[0x5d]		=	{ { HID_KEY_BRACKET_RIGHT } },		/* ] */
[0x5e]		=	{ { M_SHIFT,				/* ^ */
			    M_SHIFT | HID_KEY_6,
			    M_SHIFT } },
[0x5f]		=	{ { M_SHIFT,				/* _ */
			    M_SHIFT | HID_KEY_MINUS,
			    M_SHIFT } },

/* 0x60 */
[0x61]		=	{ { HID_KEY_A } },
[0x62]		=	{ { HID_KEY_B } },
[0x63]		=	{ { HID_KEY_C } },
[0x64]		=	{ { HID_KEY_D } },
[0x65]		=	{ { HID_KEY_E } },
[0x66]		=	{ { HID_KEY_F } },
[0x67]		=	{ { HID_KEY_G } },
[0x68]		=	{ { HID_KEY_H } },
[0x69]		=	{ { HID_KEY_I } },
[0x6a]		=	{ { HID_KEY_J } },
[0x6b]		=	{ { HID_KEY_K } },
[0x6c]		=	{ { HID_KEY_L } },
[0x6d]		=	{ { HID_KEY_M } },
[0x6e]		=	{ { HID_KEY_N } },
[0x6f]		=	{ { HID_KEY_O } },
[0x70]		=	{ { HID_KEY_P } },
[0x71]		=	{ { HID_KEY_Q } },
[0x72]		=	{ { HID_KEY_R } },
[0x73]		=	{ { HID_KEY_S } },
[0x74]		=	{ { HID_KEY_T } },
[0x75]		=	{ { HID_KEY_U } },
[0x76]		=	{ { HID_KEY_V } },
[0x77]		=	{ { HID_KEY_W } },
[0x78]		=	{ { HID_KEY_X } },
[0x79]		=	{ { HID_KEY_Y } },
[0x7a]		=	{ { HID_KEY_Z } },
[0x7b]		=	{ { M_SHIFT,				/* { */
			    M_SHIFT | HID_KEY_BRACKET_LEFT,
			    M_SHIFT } },
/* 0x7c */
[0x7d]		=	{ { M_SHIFT,				/* } */
			    M_SHIFT | HID_KEY_BRACKET_RIGHT,
			    M_SHIFT } },
/* 0x7e */
[0x7f]		=	{ { HID_KEY_BACKSPACE } },		/* DEL */

/* 0x80 - 0x9f */

/* 0xa0 - 0xbf */

/* 0xc0 - 0xdf */

[0xe0]		=	{ { M_DOWN | HID_KEY_ARROW_RIGHT } },
[0xe1]		=	{ { M_DOWN | HID_KEY_ARROW_LEFT } },
[0xe2]		=	{ { M_DOWN | HID_KEY_ARROW_UP } },
[0xe3]		=	{ { M_DOWN | HID_KEY_ARROW_DOWN } },
[0xe4]		=	{ { M_DOWN | HID_KEY_PAGE_DOWN } },	/* |||> */
[0xe5]		=	{ { M_DOWN | HID_KEY_PAGE_UP } },	/* <||| */
	/*
	 * There isn't really a good alternative for \ and |, so we steal
	 * the NO and YES keys, respectively.  Because these keys don't
	 * self-repeat, we end their key-down sequences without unwinding
	 * to HID_KEY_NONE, and let the USB host do the key repeat itself.
	 * We do this by ending the sequence with whatever HID key code
	 * is present with M_ENDSEQ.
	 */
[0xe6]		=	{ { M_ENDSEQ | HID_KEY_BACKSLASH } },	/* NO */
[0xe7]		=	{ { M_SHIFT,				/* YES */
			    M_SHIFT | M_ENDSEQ | HID_KEY_BACKSLASH } },
[0xe8]		=	{ { M_DOWN | M_META } },		/* SYM */
[0xe9]		=	{ { M_DOWN | HID_KEY_PAUSE } },		/* PAUSE */
[0xea]		=	{ { M_DOWN | M_ALT } },			/* TV/NABU */
/* 0xeb - 0xef */
[0xf0]		=	{ { M_UP | HID_KEY_ARROW_RIGHT } },
[0xf1]		=	{ { M_UP | HID_KEY_ARROW_LEFT } },
[0xf2]		=	{ { M_UP | HID_KEY_ARROW_UP } },
[0xf3]		=	{ { M_UP | HID_KEY_ARROW_DOWN } },
[0xf4]		=	{ { M_UP | HID_KEY_PAGE_DOWN } },	/* |||> */
[0xf5]		=	{ { M_UP | HID_KEY_PAGE_UP } },		/* <||| */
[0xf6]		=	{ { M_ENDSEQ } },			/* NO */
[0xf7]		=	{ { M_SHIFT } },			/* YES */
[0xf8]		=	{ { M_UP | M_META } },			/* SYM */
[0xf9]		=	{ { M_UP | HID_KEY_PAUSE } },		/* PAUSE */
[0xfa]		=	{ { M_UP | M_ALT } },			/* TV/NABU */
/* 0xfb - 0xff */
};

/*
 * Joystick data packets have the format:
 *
 *	1 0 1 F U R D L
 *	      i p i o e
 *	      r   g w f
 *	      e   h n t
 *	          t
 */
#define	JOY_LEFT	(1U << 0)
#define	JOY_DOWN	(1U << 1)
#define	JOY_RIGHT	(1U << 2)
#define	JOY_UP		(1U << 3)
#define	JOY_FIRE	(1U << 4)
#define	JOY_DIR_MASK	(JOY_LEFT | JOY_DOWN | JOY_RIGHT | JOY_UP)

/*
 * GAMEPAD_HAT_CENTERED is, conveniently, 0.  We'll also use that
 * for physically impossible combinations on a real joystick / dpad.
 */
static const uint8_t joy_to_dpad[JOY_DIR_MASK + 1] = {
[JOY_UP]		=	GAMEPAD_HAT_UP,
[JOY_UP | JOY_RIGHT]	=	GAMEPAD_HAT_UP_RIGHT,
[JOY_RIGHT]		=	GAMEPAD_HAT_RIGHT,
[JOY_DOWN | JOY_RIGHT]	=	GAMEPAD_HAT_DOWN_RIGHT,
[JOY_DOWN]		=	GAMEPAD_HAT_DOWN,
[JOY_DOWN | JOY_LEFT]	=	GAMEPAD_HAT_DOWN_LEFT,
[JOY_LEFT]		=	GAMEPAD_HAT_LEFT,
[JOY_UP | JOY_LEFT]	=	GAMEPAD_HAT_UP_LEFT,
};

/*
 * We keep 2 joystick contexts so we can report "simultaneous" movements
 * on both sticks more accurately, but we still need to have a global for
 * the "instance" we're processing while the data is coming in.
 */
static struct joy_context {
	struct queue queue;
	bool zombie;
} joy_context[2];

static void
joy_init(int which)
{
	queue_init(&joy_context[which].queue);
	joy_context[which].zombie = false;
}

static inline bool
joy_has_data_unlocked(int which)
{
	return !QUEUE_EMPTY_P(&joy_context[which].queue) ||
	       joy_context[which].zombie;
}

static void
send_joy_report(int which, uint8_t data)
{
	uint8_t dpad = joy_to_dpad[data & JOY_DIR_MASK];
	uint8_t buttons = (data & JOY_FIRE) ? GAMEPAD_BUTTON_A : 0;

	hid_gamepad_report_t report = {
		.hat		=	dpad,
		.buttons	=	buttons,
	};

	tud_hid_n_report(ITF_NUM_JOY0 + which, 0, &report, sizeof(report));
}

static struct {
	struct queue queue;
	const uint16_t *next;
	uint16_t modifiers;
	bool zombie;
} kbd_context;

static void
kbd_init(void)
{
	queue_init(&kbd_context.queue);
	kbd_context.next = NULL;
	kbd_context.modifiers = 0;
	kbd_context.zombie = false;
}

static inline bool
kbd_has_data_unlocked(void)
{
	return kbd_context.next != NULL ||
	       !QUEUE_EMPTY_P(&kbd_context.queue) ||
	       kbd_context.zombie;
}

static inline uint8_t
keymod_to_hid(uint16_t code)
{
	return M_MODS(code) >> 8;
}
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
int
main(void)
{
	extern const char version_string[];
	uint32_t now;
	uint actual_baud;

	/* TinyUSB SDK board init - initializes LED and console UART (0). */
	board_init();

	printf("NABU Keyboard -> USB HID Adapter %s\n", version_string);
	printf("Copyright (c) 2022 Jason R. Thorpe\n\n");

	printf("Disabling keyboard power.\n");
	gpio_init(PWREN_PIN);
	gpio_set_dir(PWREN_PIN, GPIO_OUT);
	kbd_setpower(false);

	printf("Initializing status LED.\n");
	led_set_sequence(ledseq_not_mounted);

	/*
	 * Sample the debug strapping pin.  If it's tied to GND, then we
	 * enable debug messages.  Once we've sampled it, we're done, so
	 * we can disable the pull-up to save a teensy bit of power.
	 */
	gpio_init(DEBUG_STRAP_PIN);
	gpio_pull_up(DEBUG_STRAP_PIN);
	debug_enabled = !gpio_get(DEBUG_STRAP_PIN);
	printf("Debug messages %s.\n", debug_enabled ? "ENABLED" : "disabled");
	gpio_disable_pulls(DEBUG_STRAP_PIN);

	printf("Initializing UART1 (NABU keyboard).\n");
	gpio_set_function(UART1_TX_PIN, GPIO_FUNC_UART);
	gpio_set_function(UART1_RX_PIN, GPIO_FUNC_UART);
	actual_baud = uart_init(uart1, NABU_KBD_BAUDRATE);
	if (actual_baud != NABU_KBD_BAUDRATE) {
		printf("WARNING: UART1 actual baud rate %u != %u\n",
		    actual_baud, NABU_KBD_BAUDRATE);
	}
	uart_set_fifo_enabled(uart1, true);
	uart_set_format(uart1, 8/*data*/, 1/*stop*/, UART_PARITY_NONE);

	/* Drain the keyboard UART of any junk that might be stuck. */
	while (uart_is_readable(uart1)) {
		uart_getc(uart1);
	}

	printf("Initializing USB stack.\n");
	tusb_init();

	printf("Initializing keyboard state.\n");
	kbd_init();

	printf("Initializing joystick state.\n");
	joy_init(0);
	joy_init(1);

 relaunch:
	printf("Resetting Core 1.\n");
	multicore_fifo_drain();
	multicore_reset_core1();

	printf("Starting UART reader on Core 1.\n");
	multicore_launch_core1(nabu_keyboard_reader);

	printf("Waiting for UART reader to be ready.\n");
	uint32_t magic = multicore_fifo_pop_blocking();
	if (magic != CORE1_MAGIC) {
		printf("ERROR: bad magic from Core 1 (0x%08x != 0x%08x)!\n",
		    magic, CORE1_MAGIC);
		goto relaunch;
	}

	printf("Enabling keyboard power.\n");
	kbd_setpower(true);

	printf("Entering main loop!\n");
	for (;;) {
		now = board_millis();
		led_task(now);		/* heartbeat LED */
		kbd_deadcheck(now);	/* check if keyboard is alive */
		hid_task(now);		/* HID processing */
		tud_task();		/* TinyUSB device task */
	}
}

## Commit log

2022-12-10 Checkpoint: LED should blink now.
2022-12-12 Sample GP22 when we start up -- it's pulled up to Vdd, but if tied to GND we enable debug messages.
2022-12-12 Use GP26 to control the power of the NABU keyboard.
2022-12-12 Fix dumb bug in kbd_getc()'s simulation case.
2022-12-13 First pass at using SYM as a META/GUI (Windows / Cloverleaf) bucky bit.
2022-12-13 Allow GP14 and GP15 to trigger simulated Cmd-c / Cmd-v sequences when touched to GND. Verified SYM -> META logic works as expected.
2022-12-13 Track whether we've seen the keyboard's RESET message. When we know we've powered off the keyboard, set have_nabu to false. This causes the deadcheck to politely state that it's waiting for the keybo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
2022-12-13 Drain the keyboard of any junk before launching the reader thread on Core 1, and wait for Core 1 to be ready before powering up the keyboard for the first time.
2022-12-13 Put the logic for "device has data" into keyboard and joystick-specific functions.
2022-12-13 Pass the current timestamp to the task functions rather than computing it each time.
2022-12-14 Cange pins used for Cmd-c / Cmd-v injection to make the PCB layout a bit better.
2022-12-14 First crack at schematic / PCB. Don't have footprint information for the DIN-6 connector yet, so there's a placeholder instead.
    [nabu-usb-keyboard.kicad_pcb, nabu-usb-keyboard.sch]
2022-12-14 Correct name in comment block.
    [nabu-usb-keyboard.sch]
2022-12-19 Improve status LED patterns.
2022-12-19 De-glitch the RS422 input in the same fashion as the NABU.
    [nabu-usb-keyboard.sch]
2022-12-19 G/C the SIMULATE_KEYSTROKES stuff. It was super useful when bringing up the board, but it's no longer needed.
2022-12-20 Update README.md
    More hardware description + BoM.
2022-12-20 Update README.md
    Clarify footprint arrangement for the resistors.
2022-12-21 Finalize the first prototype PCB.
    [nabu-usb-keyboard.kicad_pcb, nabu-usb-keyboard.sch]
2022-12-21 Fix a couple of minor schematic errors.
    [nabu-usb-keyboard-B_Cu.gbr, nabu-usb-keyboard-B_Mask.gbr, nabu-usb-keyboard-B_SilkS.gbr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]
2022-12-21 Add UF2 file of the current firmware.
2023-04-07 nabu-usb-keyboard --> nabu-keyboard-usb
    [nabu-keyboard-usb-B_Cu.gbr, nabu-keyboard-usb-B_Mask.gbr, nabu-keyboard-usb-B_SilkS.gbr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]
2023-04-09 Convert to KiCad 6 format.
    [nabu-keyboard-usb.kicad_pcb, nabu-keyboard-usb.kicad_sch]
2023-04-09 Remove KiCad 5 files.
    [nabu-keyboard-usb.sch]
2023-04-09 Fix an error in the schematic that resulted in a non-working PCB; TX+ and TX- were swapped going into the 75176.
    [nabu-keyboard-usb.kicad_pcb, nabu-keyboard-usb.kicad_sch]
2023-04-10 Update schematic PDF to rev 0.2
2023-04-10 Update PCB silkscreen to reflect rev bump and make new font/back images.
    [nabu-keyboard-usb.kicad_pcb]
2023-04-10 Regenerate Gerbers for rev 0.2 PCB.
    [nabu-keyboard-usb-B_Cu.gbr, nabu-keyboard-usb-B_Mask.gbr, nabu-keyboard-usb-B_SilkS.gbr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]
2023-04-10 Update README.md
    Remove any discussion of 12V supply -- 9V is what we want. Document the polarity protection diode.
2023-04-13 Update README.md
    Fix a couple of typos.
2023-05-21 Re-flow text for 80 columns. Add link to video about the project.

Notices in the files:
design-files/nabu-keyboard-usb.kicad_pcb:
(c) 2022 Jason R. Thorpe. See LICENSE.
